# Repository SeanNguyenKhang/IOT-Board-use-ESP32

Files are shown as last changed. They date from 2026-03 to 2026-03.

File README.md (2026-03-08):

# IOT-Board-use-ESP32
An ESP32-WROOM-32E WiFi MCU-based board, featuring a USB-style pin header for SHT3x temperature and humidity sensor integration, and a dedicated interface for DWIN HMI displays. Design in Kicad.
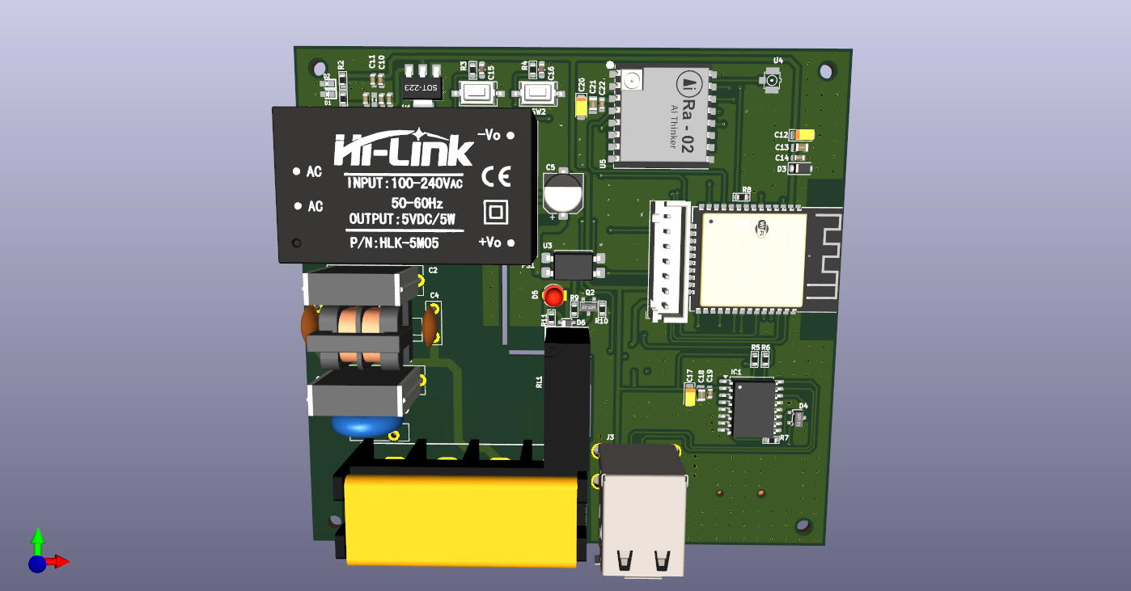
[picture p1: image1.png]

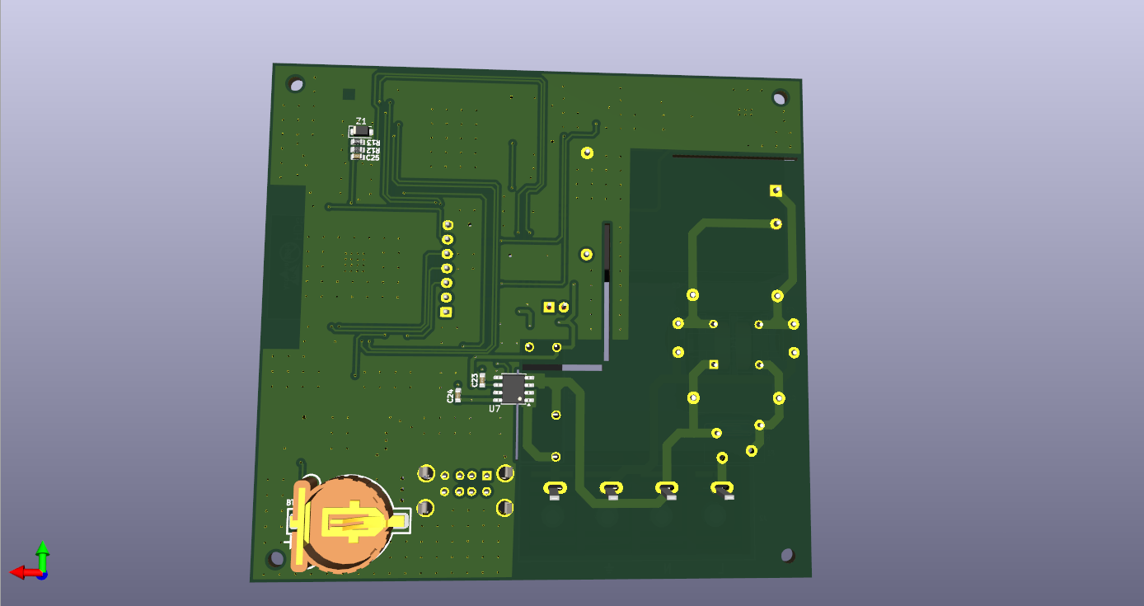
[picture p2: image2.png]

# Key Features
- ESP32-WROOM-32E MCU.
- Module Hi-Link HLK-5M05 to convert 220VAC - 5VDC.
- On-board relay for AC load control.
- Header for SHT3x sensor.
- Module Ra-02 LoRa and header for HMI display.
- USB connector for power and programming.
# Applications
This board can be used for:
- Smart Home Controller.
- Smart Switch.
- IoT Environmental Monitoring.
- Remote Device Control.
- Industrial IoT Node.
# Development Tools
Recommended tools:
- KiCad (PCB Design).
- VSCode with IDF Enviroment.
- Arduino Framework.

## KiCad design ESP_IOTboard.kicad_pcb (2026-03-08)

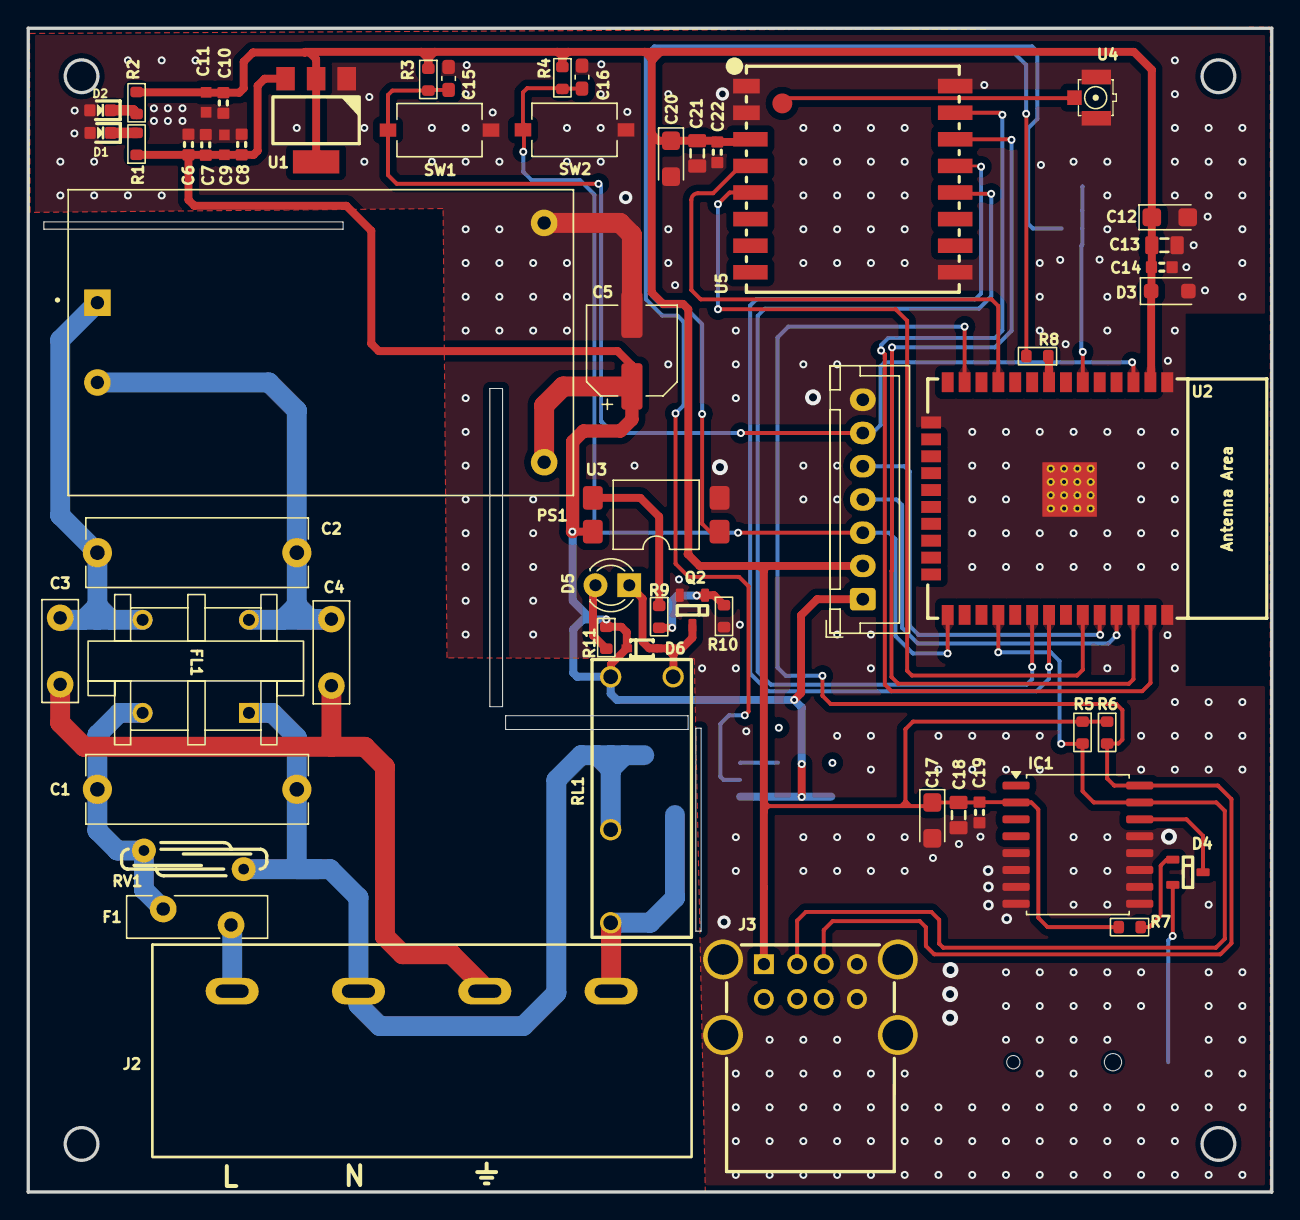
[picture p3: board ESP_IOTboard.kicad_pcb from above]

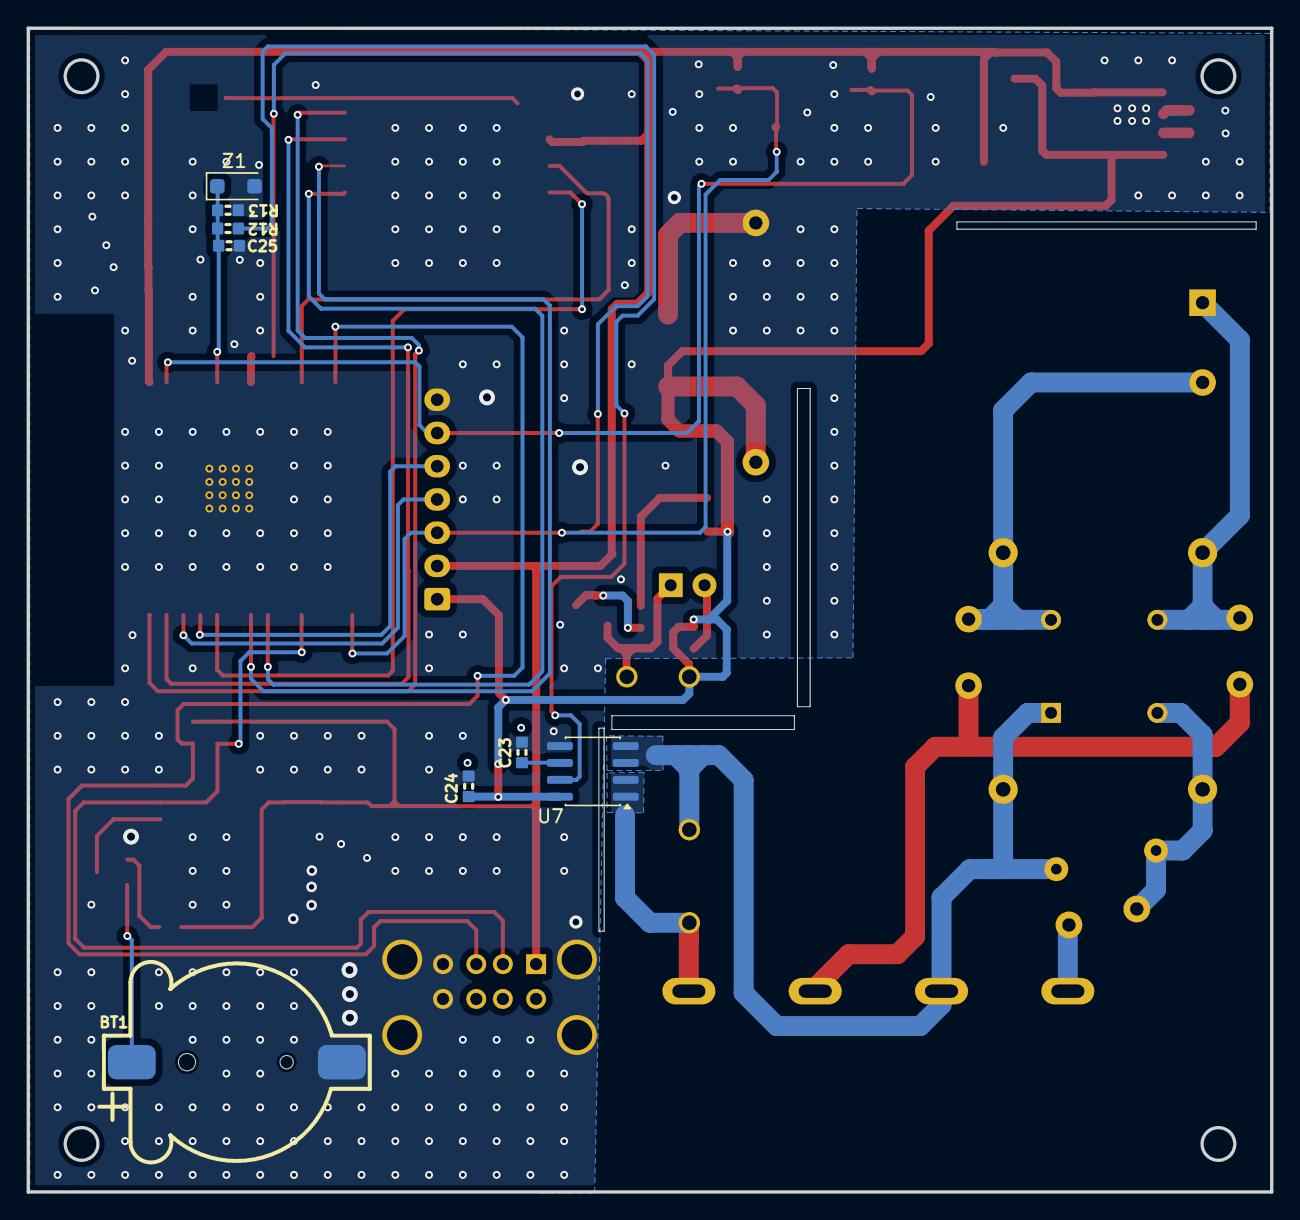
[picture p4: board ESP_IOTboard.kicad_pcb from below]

Board: 2 copper layers, 93.5 x 87.5 mm, 64 parts (8 on the bottom side), 37 nets.

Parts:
BT1: CR1220; BatteryHolder_CR1220
C1: 0.1uF/ 275VAC; C_Rect_L16.5mm_W5.0mm_P15.00mm_MKT
C2: 0.1uF/275VAC; C_Rect_L16.5mm_W5.0mm_P15.00mm_MKT
C3, C4: 10nF/1000VAC; C_Disc_D7.5mm_W2.5mm_P5.00mm
C5: 220uF/6.3x7.7/6.3V; CP_Elec_6.3x7.7
C6, C8, C10: 10uF/0603/6.3V; C_0603
C7, C14, C19, C22, C24: 100nF/0603/50V; C_0603
C9, C11: 100nF/0603/50V; SMD-0603C
C12, C17, C20: 100uF/3216/16V; CP_EIA-3216-10_Kemet-I
C13, C18, C21: 1uF/0805/25V; C_0805
C15, C16: 10uF/0603/50V; C_0603_1608Metric_Pad1.08x0.95mm_HandSolder
C23: 100nF/0603; C_0603
C25: 10nF/0603; C_0603
D1: RED/0603; LED_0603
D2: GREEN/0603; LED_0603
D3: BZT52Bxx; D_SOD-123F
D4: BAT54C; SOT23-3
D5: RED/0603; LED_D3.0mm_Red
D6: 1N4148WS; D_SOD323
F1: 300mA/250VAC; Fuse_Bourns_MF-RG500
FL1: 10mH/UU9.8 103; ACFilterChokeUU9.8
IC1: RTC_DS3231M; SOIC-16W_7.5x10.3mm_P1.27mm
J1: Conn_01x07_Pin; JST_XH_B7B-XH-A_1x07_P2.50mm_Vertical
J2: HP 9500; TerminalBlock_Screw_HB9500_4P_P9.5mm
J3: USB_A_Stacked; USB_A_Wuerth_61400826021_Horizontal_Stacked
PS1: HLK-10M05; HLK-5M05
Q2: N_Mosfet; SOT23-3
R1, R2: 2.2K/0603/5%; R_0603_1608Metric
R3, R4, R10: 10K/0603/5%; R_0603_1608Metric
R5, R6: 4.7K/0603/1%; R_0603_1608Metric
R7: 1K/0603/1%; R_0603_1608Metric
R8: 1K/0603/5%; R_0603_1608Metric
R9: 100/0603/5%; R_0603_1608Metric
R11: 470/0603/5%; R_0603_1608Metric
R12: 4.7K/0603/1%; R_0603
R13: 1.2K/0603/1%; R_0603
RL1: Relay_G5NB-1A-E_DC5; Relay_G5NB-1A-E DC5
RV1: 560V; RV_Disc_D12mm_W3.9mm_P7.5mm
SW1: Reset_button; SW_Tactile_SPST_NO_Straight_CK_PTS636Sx25SMTRLFS
SW2: Boot_button; SW_Tactile_SPST_NO_Straight_CK_PTS636Sx25SMTRLFS
U1: AMS1117 - 3.3/SOT-223; SOT233
U2: ESP32-WROOM-32E
U3: EL357N; SMDIP-4_W9.53mm_Clearance8mm
U4: Ipex; IPEX_Antena_Connector
U5: Ai-Thinker-Ra-02; MODULE_RA-02_LORA
U7: ACS712xLCTR-20A; SOIC-8_3.9x4.9mm_P1.27mm
Z1: 3V6; D_SOD-123F

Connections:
+3V3: C10.1, C11.1, C12.1, C13.1, C14.1, C17.1, C18.1, C19.1, C20.1, C21.1, C22.1, D3.1 (K), IC1.2 (VCC), J1.2, J3.1 (VBUS1), R2.1, R3.1, R4.1, R5.1, R6.1, R7.1, U1.2 (VO), U2.2 (VDD), U5.3 (VDD)
+5V: C5.1, C6.1, C7.1, C8.1, C9.1, C24.1, D6.2, J1.1, PS1.4 (+Vout), R1.1, R11.1, RL1.1, U1.3 (VI), U3.4, U7.8 (VCC)
/MCU_ESP32_WROM_32E/ESP_BOOT: C16.1, J1.3, R4.2, SW2.1, U2.25 (IO0)
/MCU_ESP32_WROM_32E/ESP_RST: C15.1, J1.6, R3.2, SW1.1, U2.3 (EN)
/MCU_ESP32_WROM_32E/ESP_RX: J1.5, U2.34 (RXD0/IO3)
/MCU_ESP32_WROM_32E/ESP_TX: J1.4, U2.35 (TXD0/IO1)
/MCU_ESP32_WROM_32E/I2C_SCL: IC1.16 (SCL), J3.3 (D1+), R6.2, U2.13 (IO14)
/MCU_ESP32_WROM_32E/I2C_SDA: IC1.15 (SDA), J3.2 (D1-), R5.2, U2.28 (IO17)
/MCU_ESP32_WROM_32E/LoRa.CS: U2.37 (IO23), U5.15 (~NSS)
/MCU_ESP32_WROM_32E/LoRa.INT: U2.33 (IO21), U5.5 (DIO0)
/MCU_ESP32_WROM_32E/LoRa.MISO: U2.31 (IO19), U5.13 (MISO)
/MCU_ESP32_WROM_32E/LoRa.MOSI: U2.36 (IO22), U5.14 (MOSI)
/MCU_ESP32_WROM_32E/LoRa.RST: U2.11 (IO26), U5.4 (~RESET)
/MCU_ESP32_WROM_32E/LoRa.SCK: U2.30 (IO18), U5.12 (SCK)
ADC: C25.1, R12.2, R13.2, U2.6 (IO34), Z1.1 (K)
Earth: C3.1, C4.2, J2.3
GND: BT1.2 (-), C5.2, C6.2, C7.2, C8.2, C9.2, C10.2, C11.2, C12.2, C13.2, C14.2, C15.2, C16.2, C17.2, C18.2, C19.2, C20.2, C21.2, C22.2, C23.2, C24.2, C25.2, D1.1 (K), D2.1 (K), D3.2 (A), IC1.5 (GND), IC1.6 (GND), IC1.7 (GND), IC1.8 (GND), IC1.9 (GND), IC1.10 (GND), IC1.11 (GND), IC1.12 (GND), IC1.13 (GND), J1.7, J3.4 (GND1), J3.8 (GND2), J3.9 (Shield), PS1.3 (-Vout), Q2.2 (S), R10.1, R13.1, SW1.2, SW2.2, U1.1 (GND), U2.1 (GND), U2.15 (GND), U2.38 (GND), U2.39 (GND), U3.2, U4.2, U5.1 (GND), U5.2 (GND), U5.9 (GND), U5.16 (GND), U7.5 (GND), Z1.2 (A)
LINE: F1.1, J2.1
NEUTRAL: C1.2, FL1.1, J2.2, RL1.2, RV1.1, U7.3 (IP-), U7.4 (IP-)
unnamed: BT1.1 (+), D4.2
unnamed: C1.1, F1.2, FL1.3, RV1.2
unnamed: D1.2 (A), R1.2
unnamed: D2.2 (A), R2.2
unnamed: D4.1, R7.2
unnamed: D5.2 (A), R11.2
unnamed: D5.1 (K), D6.1, Q2.3 (D), RL1.4
unnamed: D4.3, IC1.14 (VBAT)
unnamed: C2.1, C3.2, FL1.4, PS1.1 (AC/L)
unnamed: C2.2, C4.1, FL1.2, PS1.2 (AC/N)
unnamed: Q2.1 (G), R9.2, R10.2
unnamed: R8.2, U3.1
unnamed: R9.1, U3.3
unnamed: U4.1, U5.17 (Anaten)
unnamed: C23.1, U7.6 (FILTER)
unnamed: R12.1, U7.7 (VIOUT)
RELAY: J2.4, RL1.3, U7.1 (IP+), U7.2 (IP+)
RELAY_IN: R8.1, U2.8 (IO32)
